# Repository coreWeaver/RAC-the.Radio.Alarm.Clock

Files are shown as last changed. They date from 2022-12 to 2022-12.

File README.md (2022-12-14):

# RAC---The-Radio-Alarm-Clock ->> Open Source Project

this project is released as Open Software/ Open Hardware. All the documentation you need to build it is provided free and without any warranty.
You may modify, improve, distribute as long as you give proper credit.

I made video series with the full build tutorial, so you can see how I designed it, how everything works, the assemby and finally the testing of this device.
Here's the link for Part 1 of this series: https://youtu.be/nwrcHMGG3TY

Subscribe to my Youtube channel here: https://www.youtube.com/@coreWeaver

There's gonna be a second version of the PCB, for SMD components only. I'll upload it here as soon as I polish the details. 

If you enjoy this project you can buy me a coffee: https://ko-fi.com/coreweaver or support me here: https://paypal.me/coreWeaver 

Best,
coreWeaver - 2022

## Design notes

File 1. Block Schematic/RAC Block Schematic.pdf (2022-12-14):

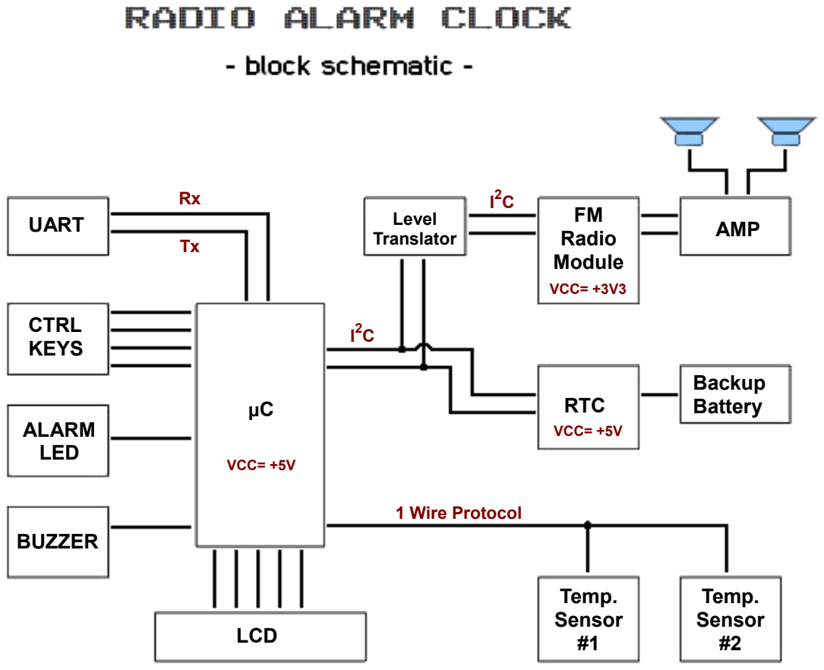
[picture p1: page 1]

UART

CTRL
KEYS

ALARM
LED

BUZZER

μC

LCD

Temp.
Sensor
#1

Temp.
Sensor
#2

RTC

Backup
Battery

Level
Translator

FM
Radio
Module

AMP

Rx

Tx

### 1 Wire Protocol

I

2C

I

2C

VCC= +3V3

VCC= +5V

VCC= +5V

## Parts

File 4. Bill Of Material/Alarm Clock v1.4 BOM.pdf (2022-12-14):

### Alarm Clock v1.4

Bill of Materials

Part's Name | Package (Raster) | Value | QTY.
D1 | DO35-10mm | 1N4004 (1N4001) | 1
R1, R4 | 0207-10mm | 330R | 2
R2 | | 549R | 1
R3, R5, R8, R9, R14, R15 | | 4k7 | 6
R6 | | 27R | 1
R7, R11, R12 | | 1k | 3
R10 | | 10R | 1
C1, C16 | 2.5mm, Dia.6mm | 100u electrolytic | 2
C2, C4 | | 10uF | 2
C18 | | 1uF electrolytic | 1
C3, C5, C6, C9, C10, C11, C14, C15, C17 | 2.5mm | 100nF | 9
C7, C8 | | 22pF | 2
C12 | | 1nF | 1
T1 | TO92 | BC547 | 1
Q1, Q2 | | 2N7000 | 2
IC1 | TO220 | 7805 | 1
IC2 | TO92 | LM317 | 1
IC3 | DIP28 | ATMEGA328P_DIP28 | 1
IC4 | DIP08 | DS1307 | 1
IC5 | DIP08 | TDA7052A | 1
XTAL1 | HC49U70 | 16MHz | 1
XTAL2 | XTAL_CYL_S | 32.768kHz | 1
LED1 | LED 3mm | Blue LED | 1
POT Volume | TRIMMER_H | 10K | 1
BAT1 | CR2032 Holder TH | Backup 3V CR2032 Battery | 1
JP4 | 1X16-M 2.54mm V | LCD Header | 1
Buzzer | Piezo 12mm | Piezo Buzzer | 1
Speaker | 36 x 5.4mm | Ekulit LSM-36M/B 1W/ 8Ohm | 2
Temp. Sensors | TO92 and Water Proof Wired | DS18B20 | 2
FM Radio Module | Breakboard Module | TEA5767 | 1
Volume Pot. | | 1M | 1

all components with the exception of the FM Radio Module are in TH-T Packages

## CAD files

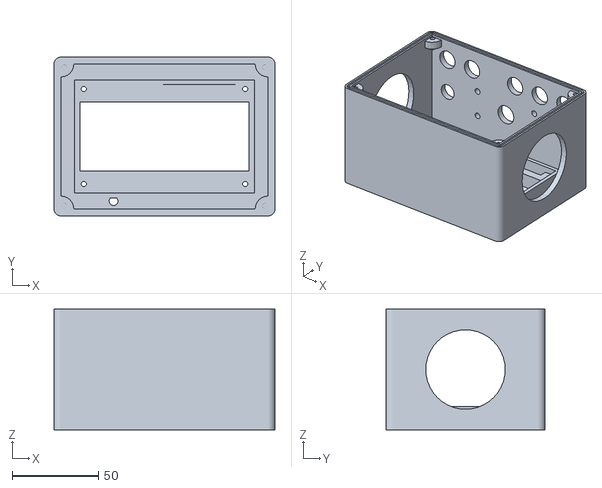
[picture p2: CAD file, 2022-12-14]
6. The Case - 3D Printed Parts (STL)/main.stl
128.0 x 92.0 x 70.0

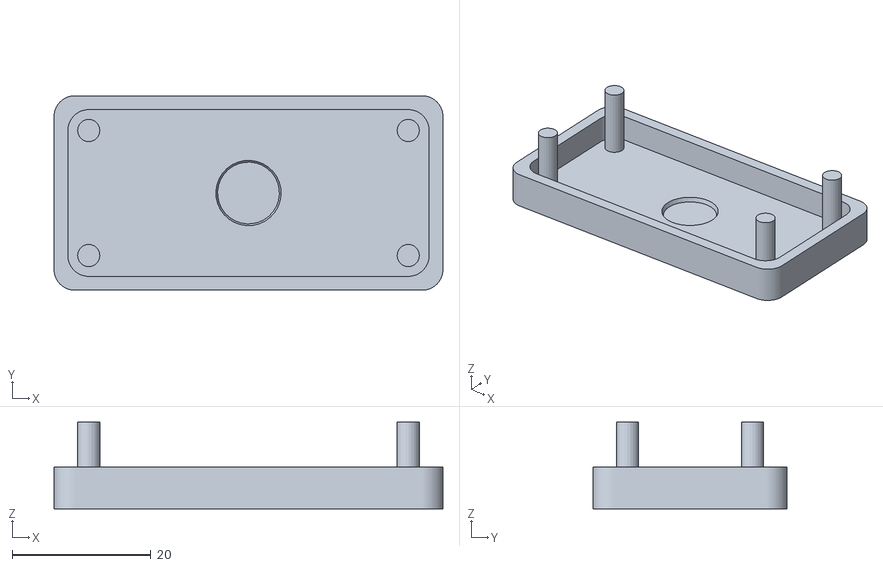
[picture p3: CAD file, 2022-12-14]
6. The Case - 3D Printed Parts (STL)/snooze.stl
56.0 x 28.0 x 12.5

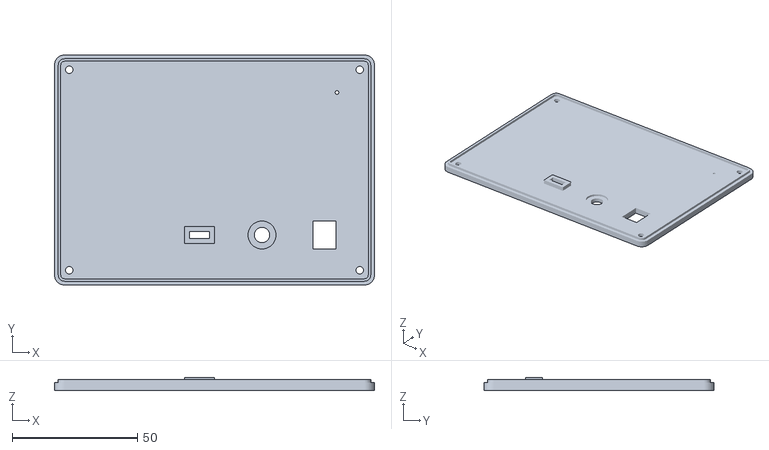
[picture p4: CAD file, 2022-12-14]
6. The Case - 3D Printed Parts (STL)/back.stl
128.0 x 92.0 x 5.00

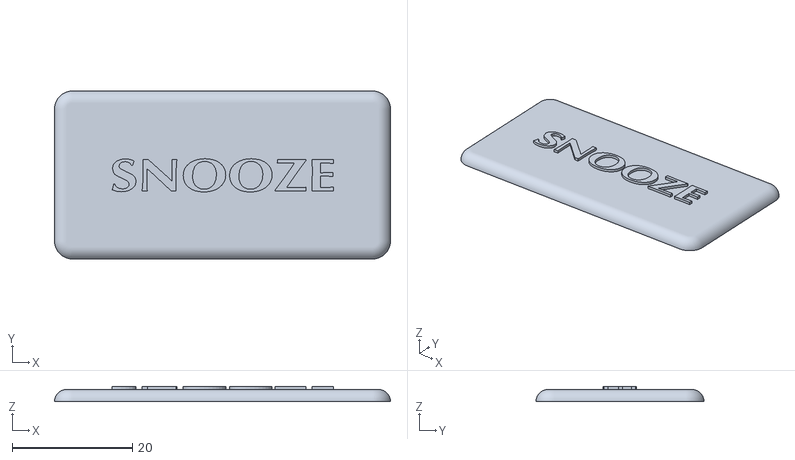
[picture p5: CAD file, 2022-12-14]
6. The Case - 3D Printed Parts (STL)/snooze cap.stl
56.0 x 28.0 x 2.50

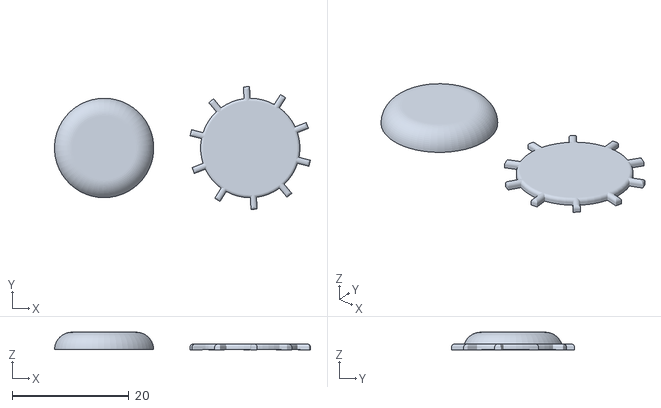
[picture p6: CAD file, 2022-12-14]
6. The Case - 3D Printed Parts (STL)/pot knob cap.stl
43.8 x 21.0 x 3.02

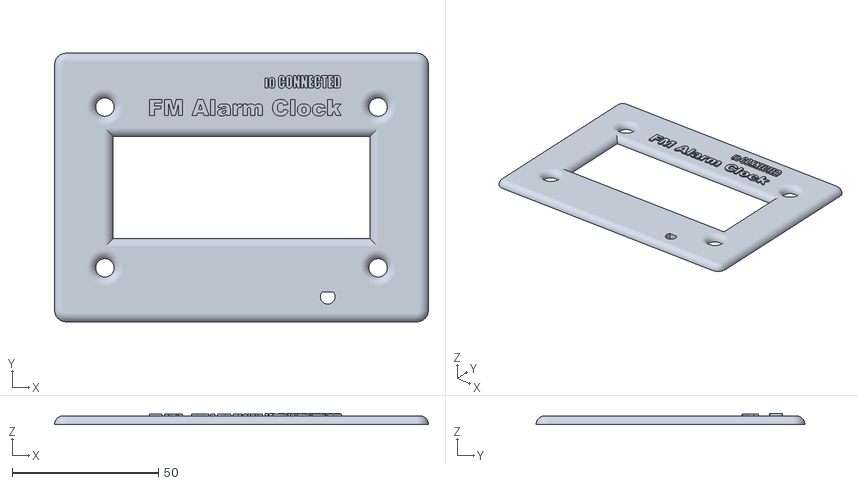
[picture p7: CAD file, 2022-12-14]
6. The Case - 3D Printed Parts (STL)/front.stl
128.0 x 92.0 x 3.80

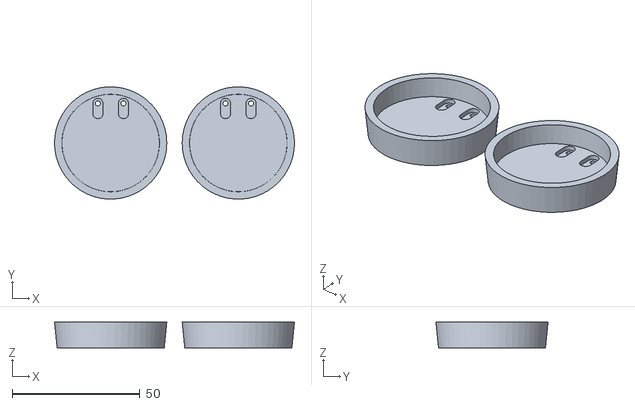
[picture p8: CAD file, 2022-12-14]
6. The Case - 3D Printed Parts (STL)/speakers caps.stl
94.0 x 43.9 x 10.0

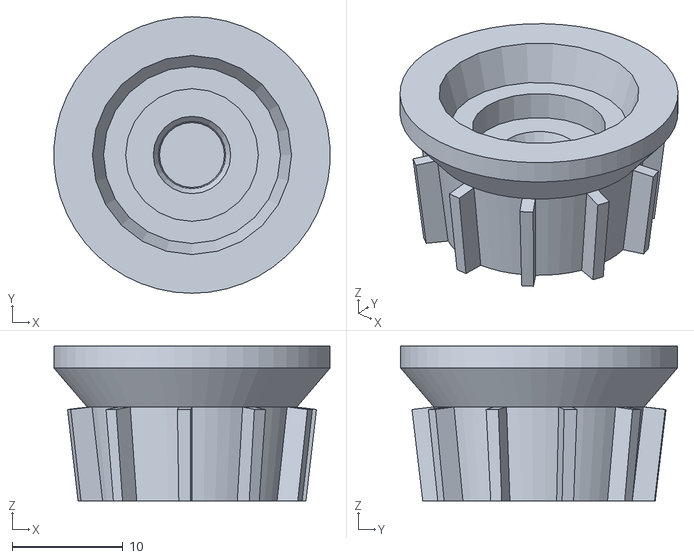
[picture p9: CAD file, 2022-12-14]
6. The Case - 3D Printed Parts (STL)/pot knob.stl
25.0 x 25.0 x 14.0

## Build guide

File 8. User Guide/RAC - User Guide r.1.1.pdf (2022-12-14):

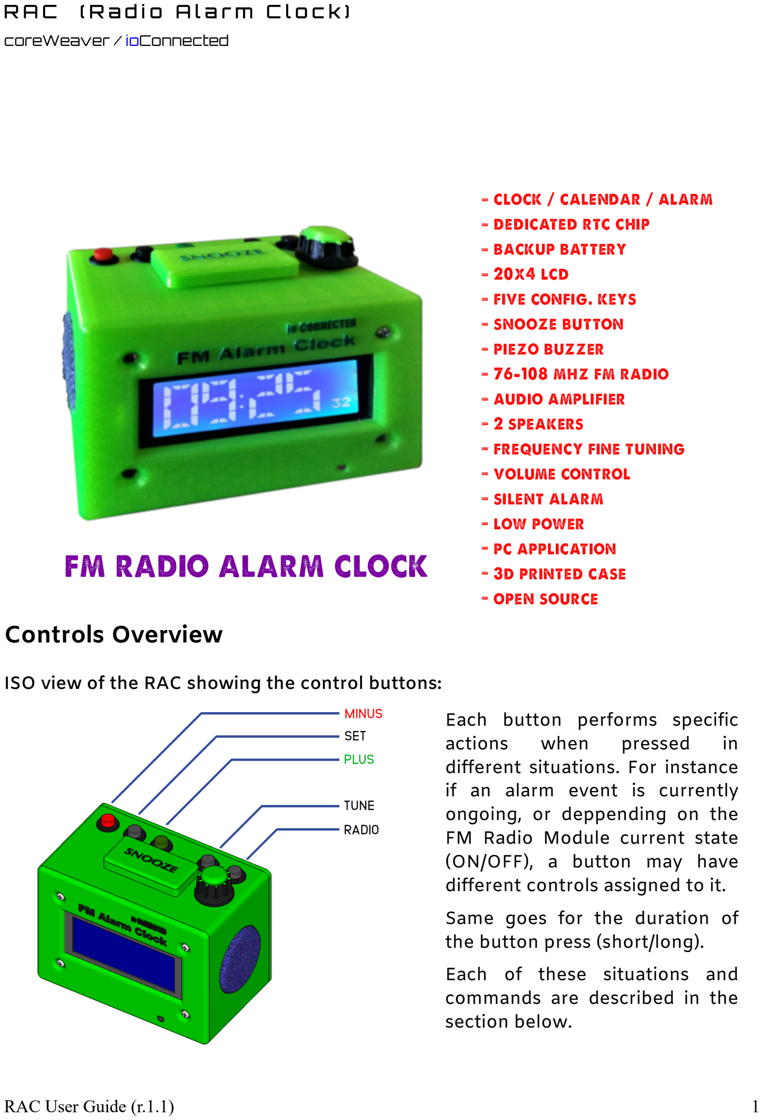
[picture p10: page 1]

R A C ( R a d i o A l a r m C l o c k )
coreWeaver / ioConnected

## Controls Overview

ISO view of the RAC showing the control buttons:

RAC User Guide (r.1.1) | 1

Each button performs specific
actions | when | pressed | in
different situations. For instance if an alarm event is currently ongoing, or deppending on the FM Radio Module current state (ON/OFF), a button may have different controls assigned to it. Same goes for the duration of the button press (short/long). Each of these situations and commands are described in the section below.

- Pressing the "RADIO" button will toggle the FM Radio ON/OFF
- Pressing both the "RADIO" and the "SET" buttons at the same time will change the LCD's Backlight Mode. There are two illuminations mode available:
1. Backlight Always ON
2. Auto Dimming 2 seconds after the last button press
- Pressing the "PLUS" button while the Radion is ON will switch to the next available Radio station
- Pressing the "MINUS" button while the Radion is ON will switch to the previous Radio station
- Pressing the "PLUS" button while the Radio is OFF will show the current Date and the measured Temperature, if one or more temp. Sensors are detected
- Pressing the "MINUS" button while the Radio is OFF will show the current Alarm configuration (Set, Time, Type of Alarm)
- Pressing the "TUNE" key while the Radio is ON will open the "Fine Tuning" submenu
- To slowly increase the current radio station's frequency press "PLUS" while in the "Fine Tuning" submenu
- To slowly decrease the current radio station's frequency press "MINUS" while in the "Fine Tuning" submenu
- Pressing the "SET" button in the "Fine Tuning" menu will accept the new frequency value for the selected radio station. This new value will also remain saved in the microcontroller's EEPROM
- Pressing the "TUNE" key when the radio is OFF will enter the UART Utility Mode. In this mode the Radio Alarm Clock will accept READ, WRITE and ERASE commands coming from a computer running the special RAC application. You'll need to use an USB – UART converter to establish the communication with the computer.

Pressing the "SET" key (long press) will enter the configuration main menu.
You can use the "PLUS", "MINUS" and "SET" keys to navigate and change the values. The available options are:
- Set new Time
- Set new Date
- Set new Alarm
- Alarm Options

Setting new Time
for each "Hour", "Minute", "Second" use the "PLUS" / "MINUS" keys to increase or decrease the value. When you're done press the "SET" key. The new Time value will be also written in the RTC's EEPROM. Since the RTC is battery backed up the Time and Data values will not be affected incase of power failure.

Setting new Date
same as above.

Setting new Alarm
same as above. The new Alarm will overwrite any pre-existent Alarms. The Time and Type of the Alarm will be written in the microcontroller's EEPROM and they will be preserved incase of a power failure.

Alarm Options
you can change the way the Radio Clock will behave when an Alarm has been detected. You can deactivate it or choose one of the three types of alarms:
- Wake up with Radio
- Buzzer Alarm
- Light Only

When an Alarm event begins the RAC will react according the the Alarm type which has been set. It will either turn ON the radio, or use it's internal piezo buzzer to acustically signal the alarm or it will remain silent indicating the alarm by flashing the LCD's backlight and the internal LED.

The "SNOOZE" button:

- if there's currently no alarm, a short press will shortly illuminate the display
- a long press will illuminate the display and will completely disable any alarm

While an Alarm is being signaled, pressing the "SNOOZE" button will pause the alarm for 5 minutes. This can happen 3 consecutive times. After that any "SNOOZE" short press will stop and postpone the Alarm for the exact time of the next day.
A long "SNOOZE" press will disable the alarm.

coreWeaver / ioConnected 2022

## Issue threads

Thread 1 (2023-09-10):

Radio not working

KeenVox, 2023-09-10:
Hey there,

I build your project and so far everything seems to work exceopt the radio. When I start the devices I get a constand buzzing noise from both speakers. I send some Radio station via UART but sadly it does not change anything. The volume pot does not change the noise volume.
Any idead, where to start troubleshooting? Thank you!

coreWeaver, 2023-09-26:
hey,
I would try using another radio module. I think the one you used it's not compatible with the firmware or it may be broken.
About the volume potentiometer not working, that's an audio amp IC related problem. make sure your TDA7052 is the "A" version. The "7052 without A" doesn't have a volume control pin.

Closed 2023-09-26.

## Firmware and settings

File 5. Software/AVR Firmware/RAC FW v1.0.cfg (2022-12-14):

[COMPILER-CHIP]
Chip=2313def.dat
XRAM=0
Waitstate=0
XA=0
Stacksize=40
Framesize=32
Sstack=16
[COMPILER-OUTPUT]
Report vars=0
Optimize=1
Binary File=1
Hexadecimal File=1
Report File=1
Debug File=1
Error File=1
ASM File=0
LST File=0
OBJ File=1
SWAP File=0
[COMPILER-COMMUNICATION]
Baudrate=9600
Frequency=4000000
[COMPILER-I2C]
Scl=0
Sda=0
[COMPILER-LCD]
DB7=PORTB.7
DB6=PORTB.6
DB5=PORTB.5
DB4=PORTB.4
E=PORTB.3
RS=PORTB.2
LCD=1
BUS mode=0
DATA mode=0
LCD address=C000
LCD-RS=8000
[COMPILER-MISC]
Size Warning=1
1wire=PORTB.0
[COMPILER-SPI]
HW SPI=0
SPICLOCK=13
SPISS=13
SPIMOSI=14
SPIMISO=15

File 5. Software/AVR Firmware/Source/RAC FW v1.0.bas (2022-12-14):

'----------------------------------------------------------------------------------------
'                               Radio Alarm Clock - Firmware
'
'
'
' This program is open source. You can redistribute it and/or modify it under the terms
' of the GNU General Public License as published by the Free Software Foundation, either
' version 3 of the License, or (at your option) any later version.
'
' This program is distributed WITHOUT ANY WARRANTY; without even the implied warranty
' of MERCHANTABILITY or FITNESS FOR A PARTICULAR PURPOSE. See the GNU General Public
' License for more details.
'
' <https://www.gnu.org/licenses/>
'
'
'
'                                                  June 2022 - coreWeaver / ioConnected
'----------------------------------------------------------------------------------------

$regfile = "m328pdef.dat"
$crystal = 16000000
$baud = 19200
$hwstack = 256
$swstack = 256
$framesize = 256

Config Single = Scientific , Digits = 3

'---- UART Config ----
Config Com1 = 19200 , Synchrone = 0 , Parity = None , Stopbits = 1 , Databits = 8 , Clockpol = 0
Open "com1:" For Binary As #1
Config Serialin = Buffered , Size = 50 , Bytematch = All
Disable Serial

'---- LCD Config ----
Config Lcdpin = Pin , Db4 = Portd.4 , Db5 = Portd.5 , Db6 = Portd.6 , Db7 = Portd.7 , E = Portd.3 , Rs = Portd.2
Config Lcd = 20 * 4
Initlcd
Cursor Off
Cls

'---- Timer 0 is used for LCD Backlight Time Interval ----
Config Timer0 = Timer , Prescale = 1024
Const Timer0_reload = 100                                   'OVF in 10mS (100Hz)
On Timer0 Timer0_isr
Enable Timer0
Stop Timer0

'---- Timer 2 is used for Alarm ----
Config Timer2 = Timer , Prescale = 1024
Const Timer2_reload = 100                                   'OVF in 10mS (100Hz)
On Timer2 Timer2_isr
Enable Timer2
Stop Timer2

'---- LCD Backlight ----
Config Portb.3 = Output
Lcd_bkl Alias Portb.3
Set Lcd_bkl

'---- Test LEDs (sourcing mode) ----
Config Portc.3 = Output
Led Alias Portc.3
Reset Led

'---- Buzzer ----
Speaker Alias Portc.2

'---- Keys ----
Config Pinb.0 = Input
Portb.0 = 1
Set_key Alias Pinb.0

Config Pinb.1 = Input
Portb.1 = 1
Plus_key Alias Pinb.1

Config Pinb.2 = Input
Portb.2 = 1
Minus_key Alias Pinb.2

Config Pinb.4 = Input
Portb.4 = 1
Snooze_key Alias Pinb.4

Config Pinb.5 = Input
Portb.5 = 1
Radio_key Alias Pinb.5

Config Pinc.1 = Input
Portc.1 = 1
Tune_key Alias Pinc.1

'---- Temperature Sensors (DS1820) / 1Wire Protocol ----
Config 1wire = Portc.0
$lib "ds1307clock.lib"                                      ' modified lib

'---- I2C's SCL and SDA pins ----
Config Sda = Portc.4
Config Scl = Portc.5

'---- Ds1307 RTC - I2C Address ----
Const Ds1307w = &HD0
Const Ds1307r = &HD1

'---- Radio Module - I2C Address ----
Const Tea5767w = &HC0
Const Tea5767r = &HC1

Const Module_frequency = 32768
Const Frequency = 225000

Config Clock = User                                         ' this will dim the bytes automatic
Config Date = Mdy , Separator = Slash

'---- Special LCD characters ----
Deflcdchar 0 , 12 , 14 , 15 , 15 , 15 , 15 , 15 , 15
Deflcdchar 1 , 15 , 15 , 15 , 15 , 15 , 15 , 14 , 12
Deflcdchar 2 , 31 , 15 , 7 , 32 , 32 , 32 , 32 , 32
Deflcdchar 3 , 31 , 30 , 28 , 32 , 32 , 32 , 32 , 32
Deflcdchar 4 , 32 , 32 , 32 , 32 , 32 , 7 , 15 , 31
Deflcdchar 5 , 32 , 32 , 32 , 32 , 32 , 28 , 30 , 31
Deflcdchar 6 , 6 , 14 , 30 , 30 , 30 , 30 , 30 , 30
Deflcdchar 7 , 30 , 30 , 30 , 30 , 30 , 30 , 14 , 6

'---- Variables ----
Dim Pll As Single
Dim Pll_freq As Word
Dim 1st As Byte
Dim 2nd As Byte
Dim 3rd As Byte
Dim 4th As Byte
Dim 5th As Byte

Dim Radio_freq(9) As Single                                 'Max 9 Radio Stations
Dim Station(9) As String * 16
Dim F(9) As String * 7

Dim R_station As Byte
Dim Radio_station As Byte
Dim W As String * 5

Dim Timeout As Integer
Dim Timeout_sec As Integer

Dim Temp_var As Integer

Dim Weekday As Byte
Dim X As Byte
Dim Pos1 As Byte , Pos2 As Byte , Pos3 As Byte , Pos4 As Byte

Dim Hh As Integer , Mm As Integer , Ss As Integer
Dim Dd As Integer , Mn As Integer , Yy As Integer
Dim Al_hh As Integer , Al_mm As Integer , Al_ss As Integer

Dim Hour As String * 2 , Minute As String * 2 , Second As String * 2
Dim Day As String * 2 , Month As String * 2 , Year As String * 2
Dim H1 As String * 1 , H2 As String * 1 , M1 As String * 1 , M2 As String * 1

Dim Newtime As String * 8 , Newdate As String * 8
Dim Alarm_time As String * 8

Dim Al_hh_str As String * 2 , Al_mm_str As String * 2

Dim Alarm_type As Integer

Dim Is_leap_year As Bit
Reset Is_leap_year

Dim Mycounter As Integer
Dim A As Integer

Dim Exitvar As Bit
Reset Exitvar

Dim Ch As Byte

Dim Light_on As Bit
Reset Light_on

Dim Long_press As Bit
Reset Long_press

Dim Press_time As Integer
Press_time = 0

Dim Alarm_is_set As Bit
Reset Alarm_is_set

Dim Set_key_time As Integer

Dim Timeout_flag As Bit
Reset Timeout_flag

Dim Snooze_long_press As Bit
Reset Snooze_long_press

Dim Snooze_press_time As Integer

Dim Do_once As Bit
Reset Do_once

Dim Radio As Bit
Reset Radio

Dim Exit_var As Bit
Reset Exit_var

Dim Rtc_menu As Integer

Dim Exit_menu As Bit
Reset Exit_menu

Dim Lcd_on As Bit
Reset Lcd_on

Dim Alarm_duration As Integer

Dim Al_type As Integer
Dim Once As Bit
Reset Once

Dim Timeout2 As Integer
Dim Timeout2_sec As Integer

Dim T2_1min_flag As Bit , T2_3min_flag As Bit
Dim Repeat_alarm As Integer
Dim Alarm_flag As Bit

Dim Timeout3 As Integer
Dim Onetime As Bit
Reset Onetime
Dim Dat_s As String * 8
Dim Decival As Byte
Dim Dsid(8) As Byte
Dim Nr As Byte
Dim Sc(9) As Byte
Dim T As Long
Dim T1 As Integer
Dim Tmp As Byte
Dim Temperature As String * 5
Dim Tempdecimal As String * 2
Dim Tempunit As String * 3

Dim U As Integer
Dim S_nr As Integer
Dim V As String * 1
Dim Ts_len As Integer

Dim Timeout_alarm_off As Integer

Dim Rxvalue As String * 32
Rxvalue = ""

Dim Rx_str As String * 32
Dim Rx_flag As Bit
Reset Rx_flag

Dim Rx_header As String * 1
Dim Rx_lastchar As String * 1
Dim S_pos As String * 1
Dim Station_pos As Byte
Dim At_pos As Integer , Name_chars As Integer , Freq_chars As Integer

Dim I As Integer

Dim Rd_1st_byte As Byte

Dim Address As Dword
Dim J As Byte
Dim Ad_s As Dword
Dim Ad_f As Dword

'---- Subroutines ----
Declare Sub Char0(byval X As Byte)
Declare Sub Char1(byval X As Byte)
Declare Sub Char2(byval X As Byte)
Declare Sub Char3(byval X As Byte)
Declare Sub Char4(byval X As Byte)
Declare Sub Char5(byval X As Byte)
Declare Sub Char6(byval X As Byte)
Declare Sub Char7(byval X As Byte)
Declare Sub Char8(byval X As Byte)
Declare Sub Char9(byval X As Byte)
Declare Sub Minus(byval X As Byte)

Declare Sub Next_station
Declare Sub Previous_station
Declare Sub Tea5767_wr
Declare Sub Tea5767_mute

Declare Sub Set_rtc
Declare Sub Alarm
Declare Sub Stop_alarm
Declare Sub Show_date_and_temp
Declare Sub Show_alarm_details
Declare Sub Sensors_autodetect
Declare Sub Ds_temp(byval Sensor_nr As Byte)

Declare Sub Send_list
Declare Sub Default_stations
Declare Sub Load_radio_stations

Declare Sub Test_stations
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
